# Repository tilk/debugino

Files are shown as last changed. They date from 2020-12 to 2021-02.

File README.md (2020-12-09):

# Debugino

An AVR ATmega development board with GDB debugging support via DebugWIRE.
Intended for educational purposes.

## Introduction

The Debugino board contains two microcontrollers:

 * an AVR ATmega328P (the same as in the popular Arduino Nano boards),
 * an STM32F103RBT6, which acts as the programmer, debugger and USB-to-UART.

The USB interface presents two CDC ACM virtual serial ports.
The first one allows to communicate with the UART on the ATmega.
The second implements two protocols:

* STK500v2, which allows programming the board using `avrdude` or other popular programming tools,
* GDB Remote Serial Protocol, which allows debugging using `avr-gdb`.

Programming and debugging the ATmega is performed using the DebugWIRE protocol.
Therefore no special bootloader or other software is needed on the ATmega.

To reduce component count, the board does not contain a separate crystal oscillator for the ATmega.
The clock for the ATmega is generated using a timer on the STM32, set to 18 MHz.

## Preparing a board

The STM32 is programmed via a separate ISP connector which exposes the SWDIO and SWCLK signals.

The ATmega does not require a bootloader, but the fusebits need to be changed from factory settings to enable DebugWIRE and configure the system clock.
The preferred fusebits values are:

* LFUSE 0xE0,
* HFUSE 0x9F,
* EFUSE 0xFF.

There is no ISP connector for the ATmega on the board, but the required signals are available on the pins labelled B3 (MOSI), B4 (MISO), B5 (SCK) and DWI (RESET).

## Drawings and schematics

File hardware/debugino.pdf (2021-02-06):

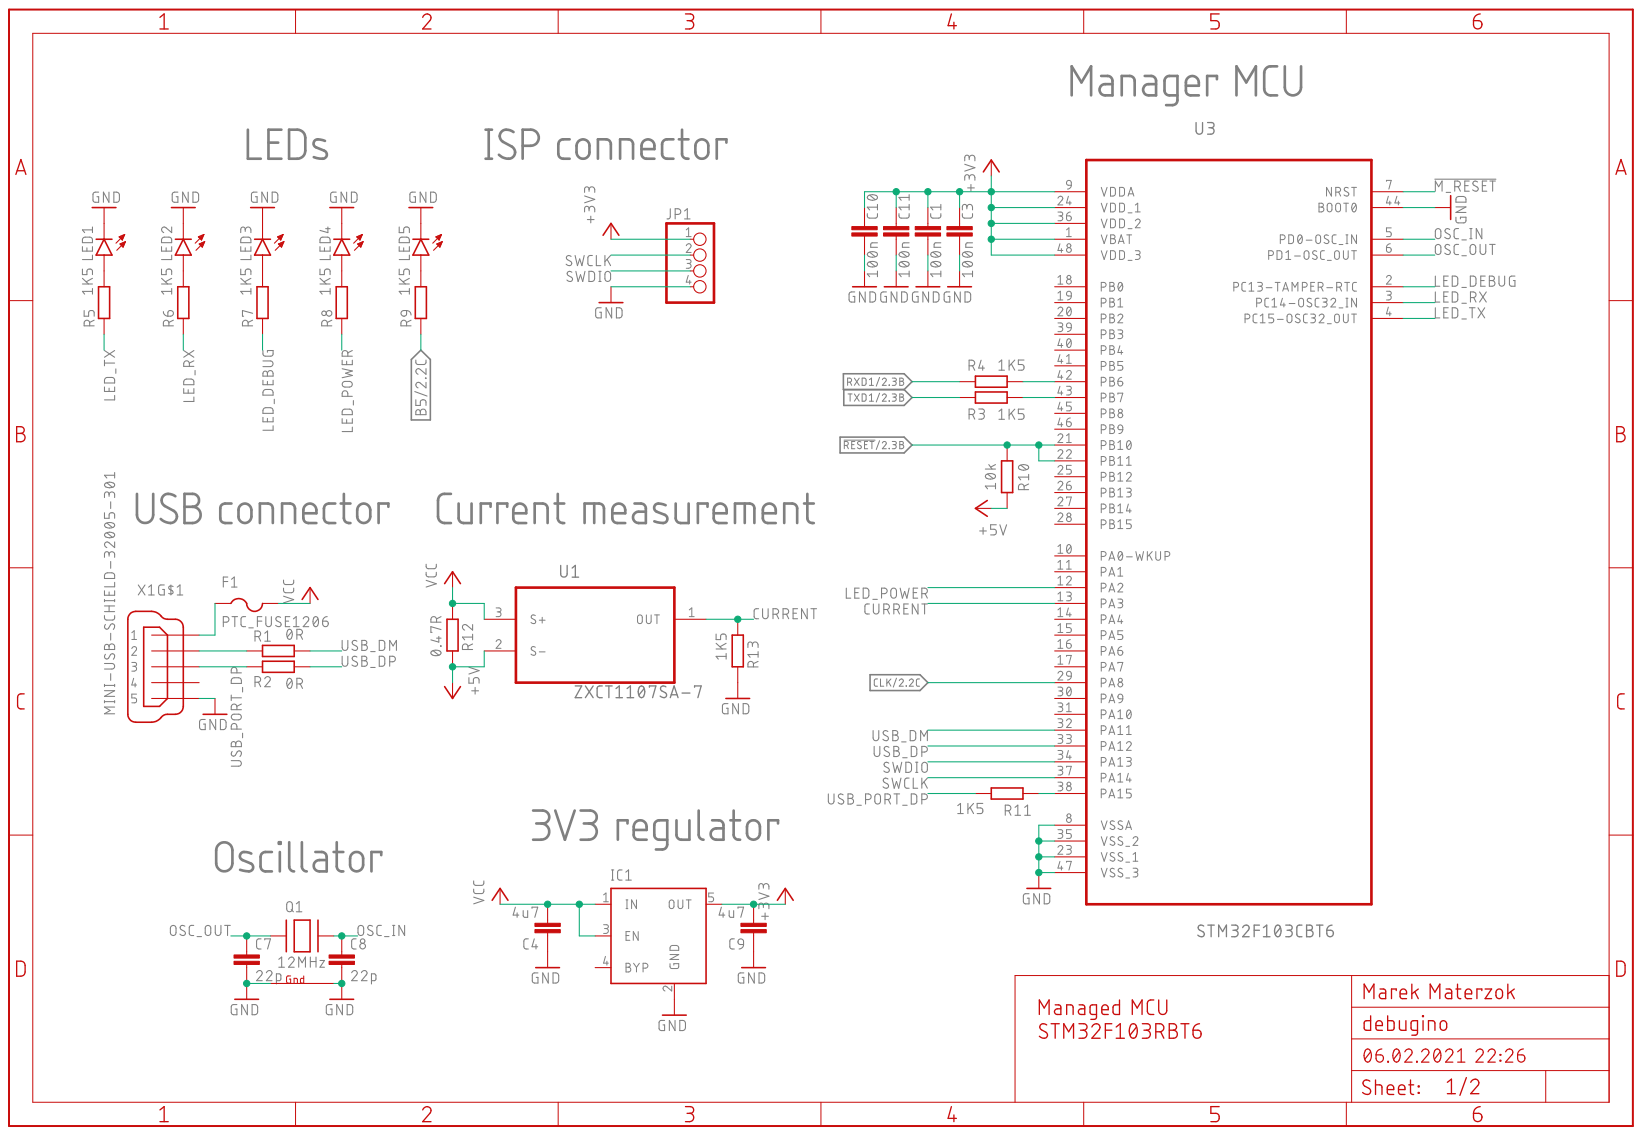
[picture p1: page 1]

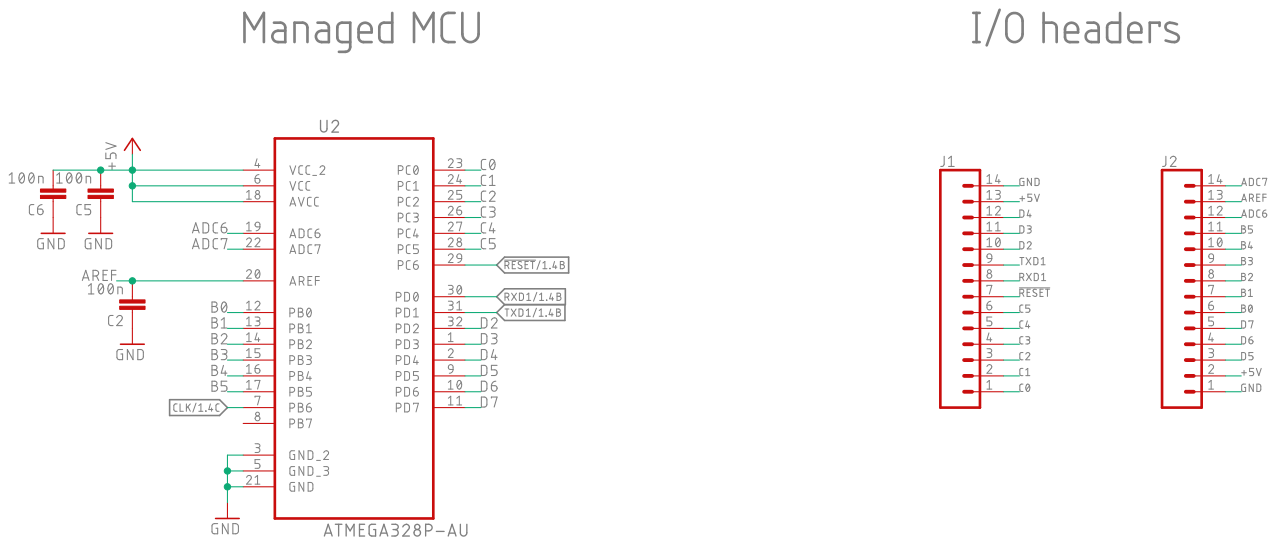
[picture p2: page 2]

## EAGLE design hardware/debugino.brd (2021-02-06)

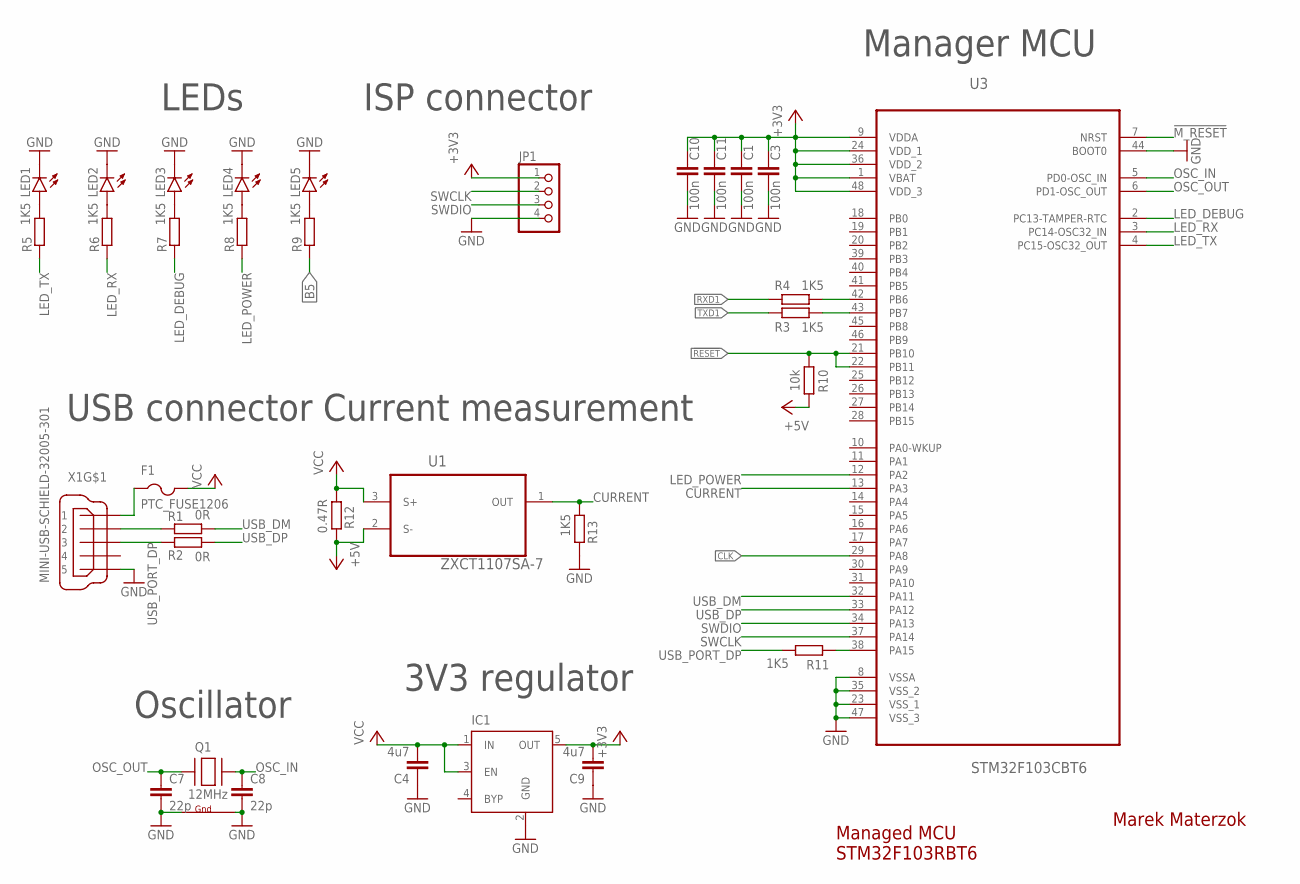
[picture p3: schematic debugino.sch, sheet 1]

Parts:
C1, C3, C10, C11: 100n; CAPC1008X70M
C4, C9: 4u7; CAPC1608X100M
C7, C8: 22p; CAPC1008X70M
F1: PTC_FUSE1206; FUSC3216X100M
IC1: MIC5219XX; SOT23-5
JP1: PINHD-1X4; 1X04
LED1, LED2, LED3, LED4, LED5: LEDCHIP-LED0603; CHIP-LED0603
Q1: 12MHz; NX3225
R1, R2: 0R; RESC1608X55M
R3, R4, R5, R6, R7, R8, R9, R11, R13: 1K5; RESC1608X55M
R10: 10k; RESC1608X55M
R12: 0.47R; RESC2012X65M
U1: ZXCT1107SA-7; SOT91P240X110-3N
U3: STM32F103CBT6; QFP50P900X900X160-48N
X1: MINI-USB-SCHIELD-32005-301; 32005-301

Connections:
!M_RESET: U3.7 (NRST)
!RESET: R10.1, U3.21 (PB10), U3.22 (PB11); also elsewhere on the board
+3V3: C1.1, C3.1, C9.2, C10.1, C11.1, IC1.5 (OUT), JP1.1, U3.1 (VBAT), U3.9 (VDDA), U3.24 (VDD_1), U3.36 (VDD_2), U3.48 (VDD_3)
+5V: R10.2, R12.2, U1.2 (S-); also elsewhere on the board
B5: R9.1; also elsewhere on the board
CLK: U3.29 (PA8); also elsewhere on the board
CURRENT: R13.1, U1.1 (OUT), U3.13 (PA3)
GND: C1.2, C3.2, C4.1, C7.2, C8.2, C9.1, C10.2, C11.2, IC1.2 (GND), JP1.4, LED1.C, LED2.C, LED3.C, LED4.C, LED5.C, Q1.2 (G2), Q1.4 (G1), R13.2, U3.8 (VSSA), U3.23 (VSS_1), U3.35 (VSS_2), U3.44 (BOOT0), U3.47 (VSS_3), X1.5; also elsewhere on the board
LED_DEBUG: R7.1, U3.2 (PC13-TAMPER-RTC)
LED_POWER: R8.1, U3.12 (PA2)
LED_RX: R6.1, U3.3 (PC14-OSC32_IN)
LED_TX: R5.1, U3.4 (PC15-OSC32_OUT)
unnamed: LED1.A, R5.2
unnamed: LED2.A, R6.2
unnamed: F1.1, X1.1
unnamed: LED3.A, R7.2
unnamed: LED4.A, R8.2
unnamed: LED5.A, R9.2
OSC_IN: C8.1, Q1.3 (X2), U3.5 (PD0-OSC_IN)
OSC_OUT: C7.1, Q1.1 (X1), U3.6 (PD1-OSC_OUT)
RXD1: R4.2; also elsewhere on the board
SWCLK: JP1.2, U3.37 (PA14)
SWDIO: JP1.3, U3.34 (PA13)
TXD1: R3.2; also elsewhere on the board
UART1_RX: R3.1, U3.43 (PB7)
UART1_TX: R4.1, U3.42 (PB6)
USB_DM: R1.2, U3.32 (PA11)
USB_DP: R2.2, U3.33 (PA12)
USB_PORT_DM: R1.1, X1.2
USB_PORT_DP: R2.1, R11.2, X1.3
USB_PULLUP: R11.1, U3.38 (PA15)
VCC: C4.2, F1.2, IC1.1 (IN), IC1.3 (EN), R12.1, U1.3 (S+)

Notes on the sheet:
LEDs
ISP connector
Oscillator
Manager MCU
USB connector
3V3 regulator
Marek Materzok
Managed MCU STM32F103RBT6
Current measurement

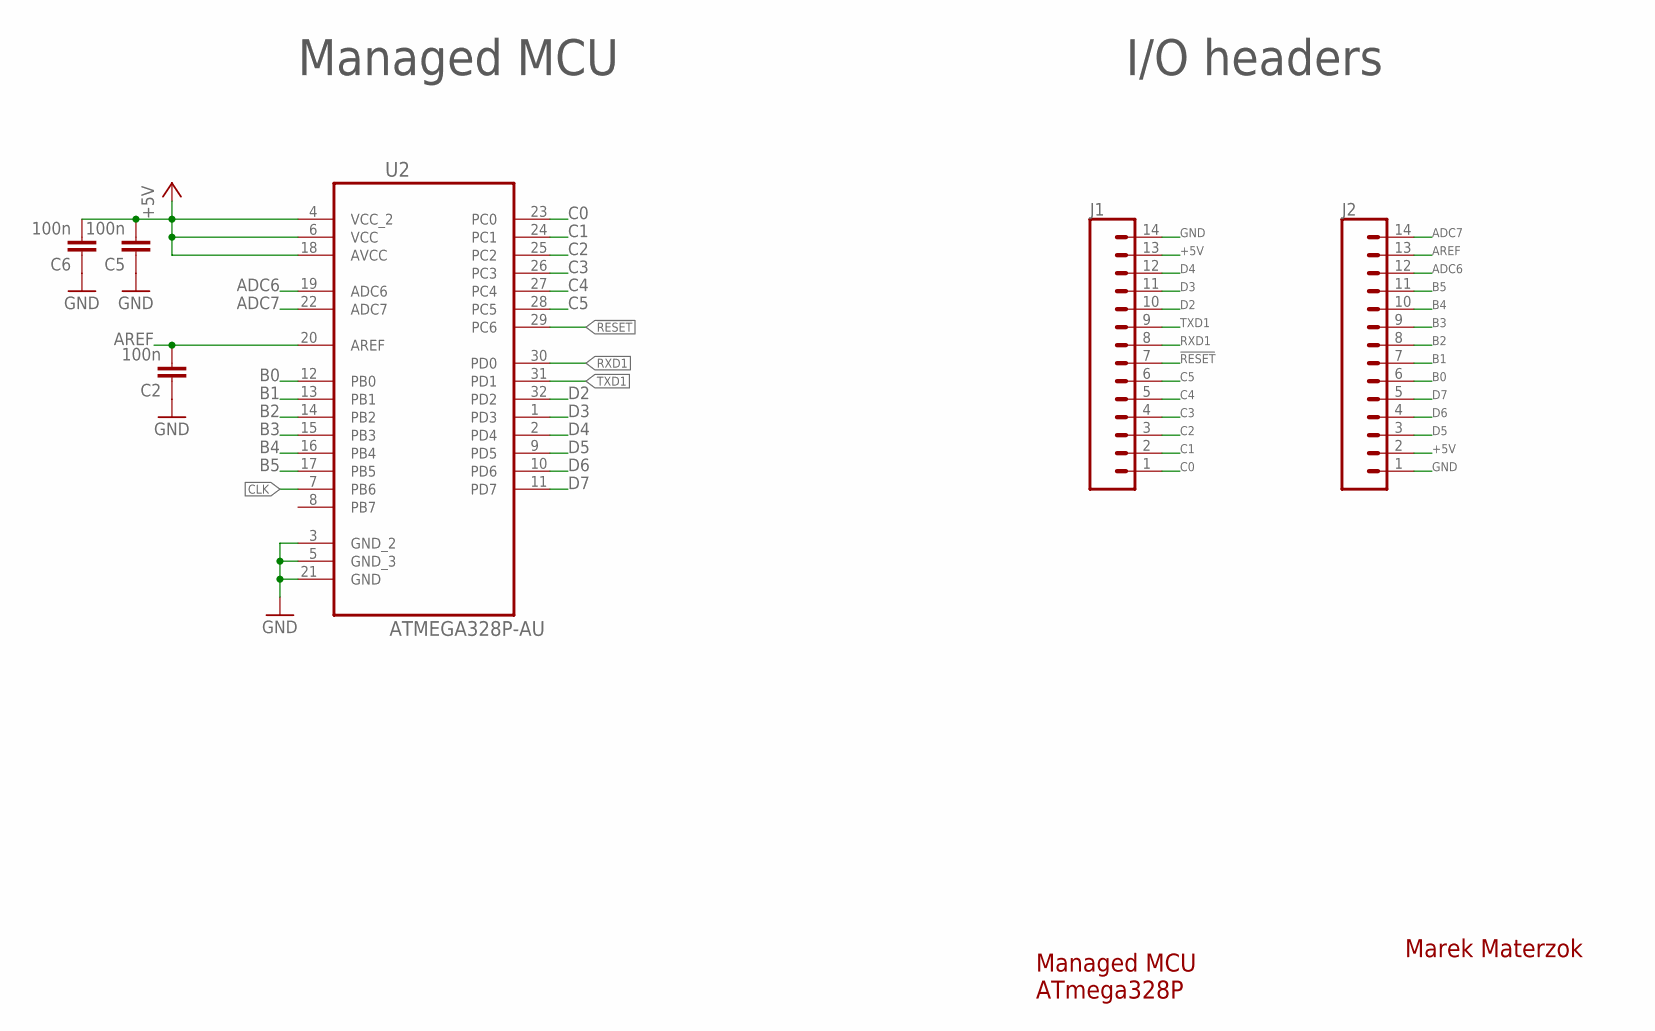
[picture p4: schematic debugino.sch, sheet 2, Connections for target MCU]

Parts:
C2, C5, C6: 100n; CAPC1008X70M
J1, J2: CONN_14; 1X14
U2: ATMEGA328P-AU; QFP80P900X900X120-32N

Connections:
!RESET: J1.7, U2.29 (PC6); also elsewhere on the board
+5V: C5.2, C6.2, J1.13, J2.2, U2.4 (VCC_2), U2.6 (VCC), U2.18 (AVCC); also elsewhere on the board
ADC6: J2.12, U2.19 (ADC6)
ADC7: J2.14, U2.22 (ADC7)
AREF: C2.2, J2.13, U2.20 (AREF)
B0: J2.6, U2.12 (PB0)
B1: J2.7, U2.13 (PB1)
B2: J2.8, U2.14 (PB2)
B3: J2.9, U2.15 (PB3)
B4: J2.10, U2.16 (PB4)
B5: J2.11, U2.17 (PB5); also elsewhere on the board
C0: J1.1, U2.23 (PC0)
C1: J1.2, U2.24 (PC1)
C2: J1.3, U2.25 (PC2)
C3: J1.4, U2.26 (PC3)
C4: J1.5, U2.27 (PC4)
C5: J1.6, U2.28 (PC5)
CLK: U2.7 (PB6); also elsewhere on the board
D2: J1.10, U2.32 (PD2)
D3: J1.11, U2.1 (PD3)
D4: J1.12, U2.2 (PD4)
D5: J2.3, U2.9 (PD5)
D6: J2.4, U2.10 (PD6)
D7: J2.5, U2.11 (PD7)
GND: C2.1, C5.1, C6.1, J1.14, J2.1, U2.3 (GND_2), U2.5 (GND_3), U2.21 (GND); also elsewhere on the board
RXD1: J1.8, U2.30 (PD0); also elsewhere on the board
TXD1: J1.9, U2.31 (PD1); also elsewhere on the board

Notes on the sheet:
Managed MCU
I/O headers
Marek Materzok
Managed MCU ATmega328P

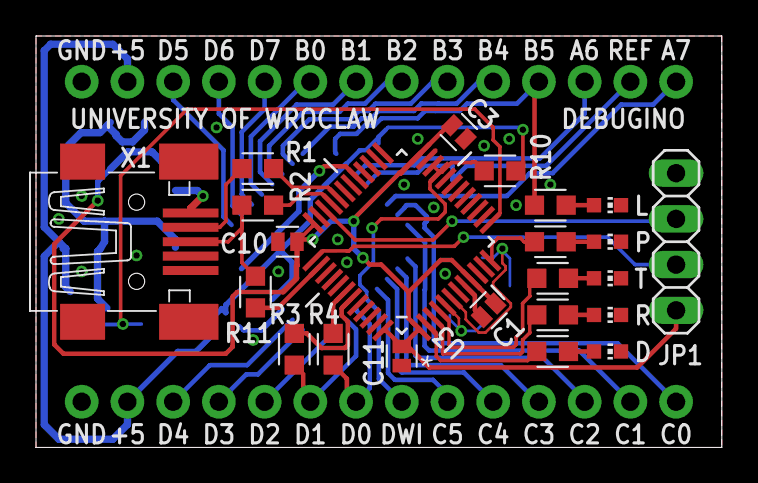
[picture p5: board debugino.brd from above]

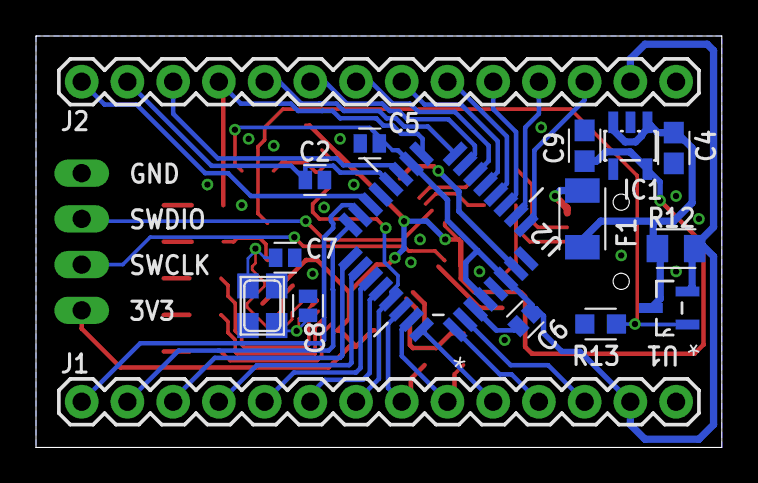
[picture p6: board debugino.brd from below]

Board: 2 copper layers, 38.1 x 22.9 mm, 39 parts (16 on the bottom side), 51 nets.

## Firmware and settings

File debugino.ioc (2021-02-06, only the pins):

Mcu.UserName=STM32F103CBTx
PA11.Signal=USB_DM
PA12.Signal=USB_DP
PA13.Signal=SYS_JTMS-SWDIO
PA14.Signal=SYS_JTCK-SWCLK
PA2.GPIO_Label=LED_POWER
PA2.Signal=GPIO_Output
PA3.GPIO_Label=CURRENT
PA3.Signal=ADCx_IN3
PA8.GPIO_Label=CLKOUT
PA8.Signal=S_TIM1_CH1
PB10.GPIO_Label=DWIRE
PB10.Signal=USART3_TX
PB6.GPIO_Label=UART_TX
PB6.Signal=USART1_TX
PB7.GPIO_Label=UART_RX
PB7.Signal=USART1_RX
PC13-TAMPER-RTC.GPIO_Label=LED_DEBUG
PC13-TAMPER-RTC.Signal=GPIO_Output
PC14-OSC32_IN.GPIO_Label=LED_RX
PC14-OSC32_IN.Signal=GPIO_Output
PC15-OSC32_OUT.GPIO_Label=LED_TX
PC15-OSC32_OUT.Signal=GPIO_Output
PD0-OSC_IN.Signal=RCC_OSC_IN
PD1-OSC_OUT.Signal=RCC_OSC_OUT

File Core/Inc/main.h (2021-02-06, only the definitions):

#define LED_DEBUG_Pin GPIO_PIN_13
#define LED_DEBUG_GPIO_Port GPIOC
#define LED_RX_Pin GPIO_PIN_14
#define LED_RX_GPIO_Port GPIOC
#define LED_TX_Pin GPIO_PIN_15
#define LED_TX_GPIO_Port GPIOC
#define LED_POWER_Pin GPIO_PIN_2
#define LED_POWER_GPIO_Port GPIOA
#define CURRENT_Pin GPIO_PIN_3
#define CURRENT_GPIO_Port GPIOA
#define DWIRE_Pin GPIO_PIN_10
#define DWIRE_GPIO_Port GPIOB
#define CLKOUT_Pin GPIO_PIN_8
#define CLKOUT_GPIO_Port GPIOA
#define UART_TX_Pin GPIO_PIN_6
#define UART_TX_GPIO_Port GPIOB
#define UART_RX_Pin GPIO_PIN_7
#define UART_RX_GPIO_Port GPIOB

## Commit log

2020-10-15 USB CDC with flow control (?)
2020-10-16 Towards working UART receive
2020-10-16 Fix DWIRE UART baudrate
    [debugino.ioc]
2020-10-21 Change pin mapping.
2020-10-23 UART break handling.
2020-10-23 Fix STK500v2 sync issue.
    [debugino.c]
2020-10-26 Fixed Z register handling
    [dwire.c]
2020-11-04 Fixes for DWIRE memory ops and SWD issues
    [debugino.c, dwire.c]
2020-11-06 Fix silly RSP bug
    [debugino.c]
2020-12-07 Towards target board.
2020-12-09 On target board, with LED support.
2020-12-09 Added hardware.
    [debugino.brd, debugino.sch]
2021-02-06 Towards current measurement.
2021-02-06 Hardware for current measurement
    [debugino.brd, debugino.sch]

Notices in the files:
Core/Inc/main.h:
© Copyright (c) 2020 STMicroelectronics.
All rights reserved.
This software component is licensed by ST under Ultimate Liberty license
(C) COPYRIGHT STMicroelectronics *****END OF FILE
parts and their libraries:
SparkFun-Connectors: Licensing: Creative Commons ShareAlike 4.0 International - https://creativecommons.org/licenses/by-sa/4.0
